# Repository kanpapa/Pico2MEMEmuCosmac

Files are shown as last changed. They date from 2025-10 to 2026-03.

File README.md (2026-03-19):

# Pico2MEMEmuCOSMAC

このリポジトリはkyo-ta04(DragonballEZ)さんの[Pico2ROMEmuBR](https://github.com/kyo-ta04/Pico2ROMEmuBR)のコードを応用して、COSMAC（CDP1802）のROM/RAMエミュレータとして動かしてみた実験的なプロジェクトです。

## 概要
- COSMAC CPUの動作クロックは1.79MHzです。
- ROM/RAMは各32KBを割り当てて確認しましたが、64KBのアドレス空間内であればカスタマイズ可能です。
- ROMにはテストプログラムとしてQ出力のLチカを組み込んでいます。rom_const.cのコメントを参照してください。
- 専用基板Rev.0.1にはSBC1802にあるインジケーターをオプション回路として追加しています。

詳細はソースをご確認ください。

## 回路図
- ブレッドボード版回路図
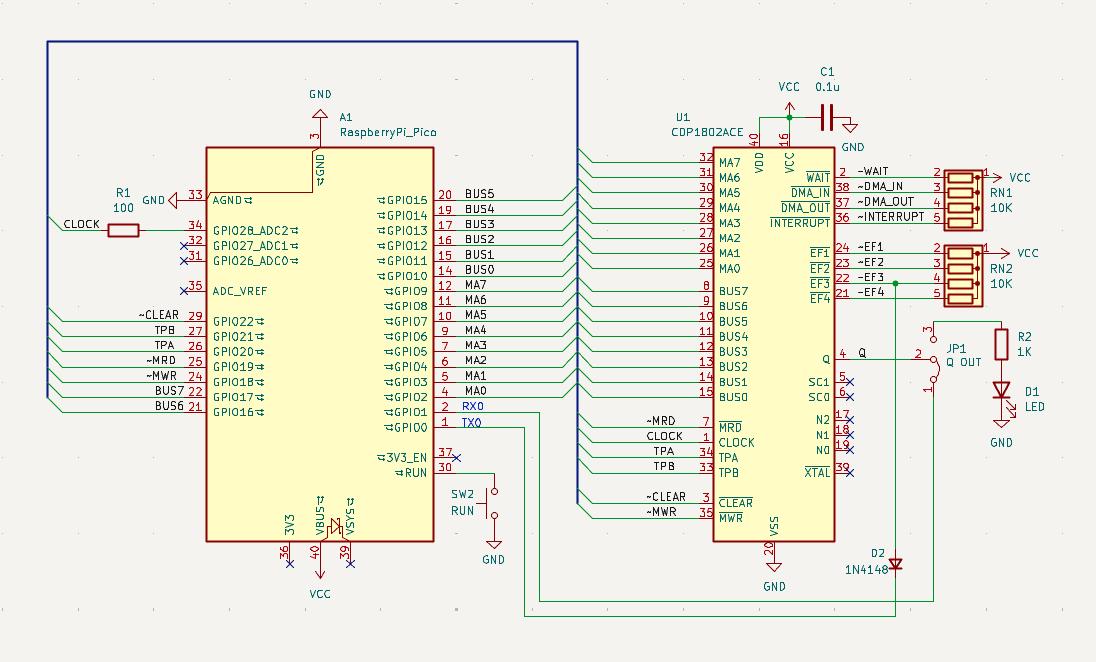
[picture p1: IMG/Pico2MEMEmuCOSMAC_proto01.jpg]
ブレッドボード版回路図

- 専用基板Rev.0.1 回路図
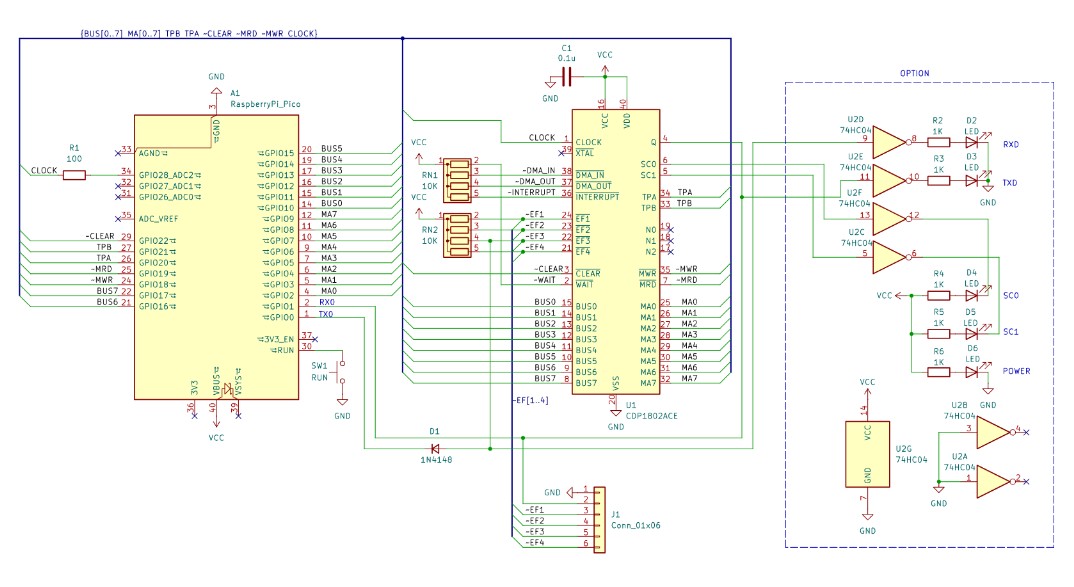
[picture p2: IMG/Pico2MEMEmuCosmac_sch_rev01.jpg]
専用基板回路図

[PDF](/IMG/Pico2MEMEmuCosmac_sch_rev01.pdf)

## PCB
- [KiCADデータ](/kicad)
- [Gerberデータ](/kicad/gerber/)
- PCB 3Dイメージ
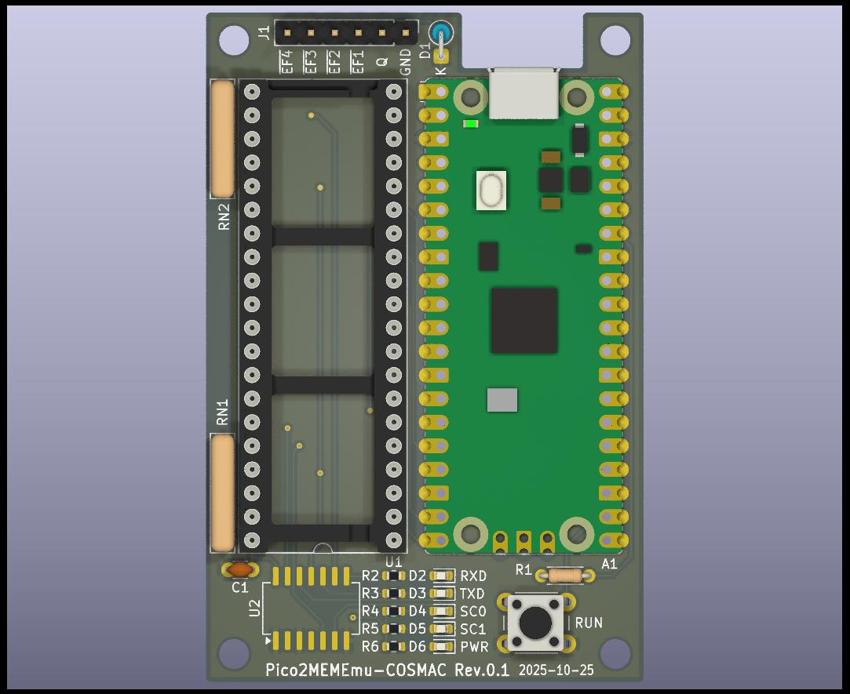
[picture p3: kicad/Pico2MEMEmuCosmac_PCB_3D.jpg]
専用基板Rev.0.1 3Dイメージ


## BOM
|Item|Qty|Reference(s)|Value|Description|Datasheet|
| --- | --- | --- | --- | --- | --- |
|1|1|A1|RaspberryPi_Pico2|Raspberry Pi Pico 2|https://akizukidenshi.com/catalog/g/g129604/|
|2|1|U1|CDP1802ACE|CDP1802ACE microprocessor|http://www.cosmacelf.com/publications/data-sheets/cdp1802.pdf|
|3|1|C1|0.1uF|リード型積層セラミックコンデンサー 0.1μF50V F 2.54mm|https://akizukidenshi.com/catalog/g/g100090/|
|4|1|D1|1N4148|汎用小信号高速スイッチング・ダイオード 1N4148 100V200mA|https://akizukidenshi.com/catalog/g/g100941/|
|5|1|R1|100|カーボン抵抗(炭素皮膜抵抗) 1/6W100Ω|https://akizukidenshi.com/catalog/g/g116101/|
|6|2|RN1,RN2|10K|集合抵抗 4素子 10kΩ|https://akizukidenshi.com/catalog/g/g111909/|
|7|1|SW1|RUN|タクトスイッチ(水色)|https://akizukidenshi.com/catalog/g/g103649/|
|8|1|U1 socket||丸ピンICソケット (40P)|https://akizukidenshi.com/catalog/g/g100034/|
|9※|1|J1|Conn_01x06|ピンヘッダー (L型) 1×6 (6P)|https://akizukidenshi.com/catalog/g/g105336/|
|10※|1|U2|74HC04|6回路入インバーター TC74HC04AF|https://akizukidenshi.com/catalog/g/g111490/|
|11※|5|D2,D3,D4,D5,D6|LED|緑色チップLED 1608 OSG50603C1E|https://akizukidenshi.com/catalog/g/g108275/|
|12※|5|R2,R3,R4,R5,R6|1k|チップ抵抗 1608 1/8W1kΩ|https://akizukidenshi.com/catalog/g/g130351/|

※9～12はオプションです。

## マニュアル
- [Visual Studio Code での Raspberry Pi Pico プロジェクトのビルド方法](/docs/raspberry-pi-pico-vscode-build.md)
- [Lチカの楽しみかた](/docs/blink.md)
- [RCA BASIC3の楽しみかた](/docs/MCBASIC3.md)
- [MCSMP Super Monitor+BASIC3の楽しみかた](/docs/MCSMP20A.md)

## 資料
- ブレッドボードで実験中の様子
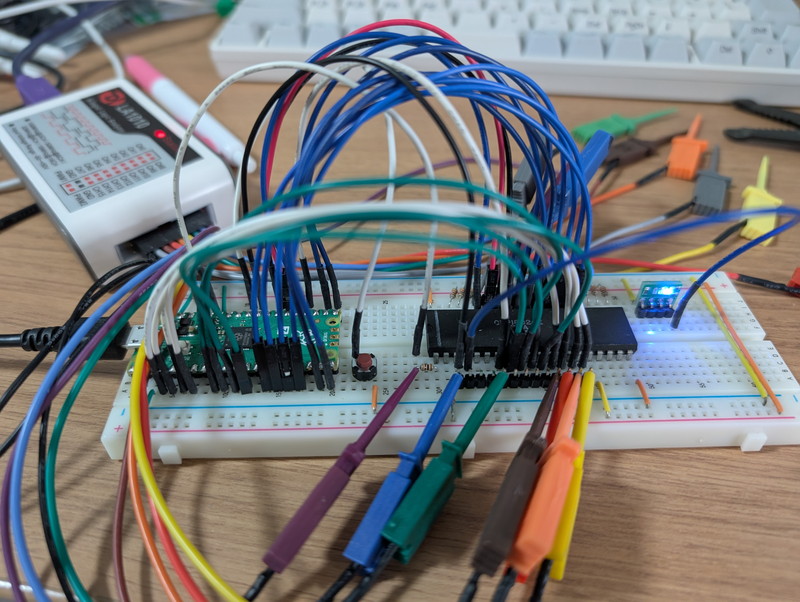
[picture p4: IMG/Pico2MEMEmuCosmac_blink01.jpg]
ブレッドボードで実験中の様子

- 専用基板に実装した状態
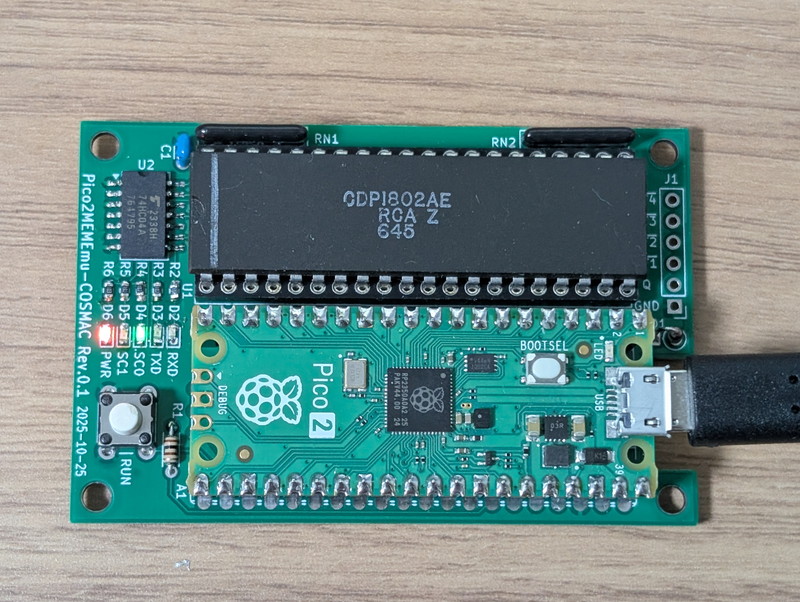
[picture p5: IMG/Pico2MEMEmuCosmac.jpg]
専用基板に実装した状態

- 専用基板で動作中の様子
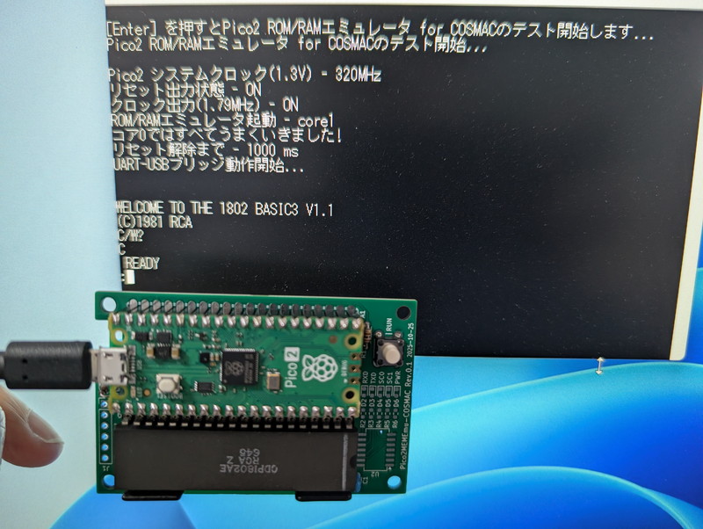
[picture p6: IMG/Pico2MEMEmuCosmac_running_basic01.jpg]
専用基板で動作中の様子


## ライセンス
本プロジェクトのソースコードは[Pico2ROMEmuBR](https://github.com/kyo-ta04/Pico2ROMEmuBR)のライセンスに従います。

## 免責事項
本ソフトウェアは現状のまま提供されます。いかなる損害についても作者は責任を負いません。

## 謝辞
kyo-ta04(DragonballEZ)さんをはじめとするPico2ROMEmuプロジェクトに関わる全ての方々

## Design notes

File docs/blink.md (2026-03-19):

# Lチカの楽しみかた
リポジトリの[rom_const.c](../rom_const.c)にはLチカのサンプルプログラムが含まれています。
これを使って基本的なCOSMACのプログラミングを理解しましょう。

## ソースコード
ソースコードはrom_const.cにコメントとして記載されていますが、blinkの部分だけで動くようにしたものを掲載しておきます。
```
0100-F8 40   START:  LDI #$40  ; Dレジスタに$40を入れる（点滅間隔のウェイトループ値）
0102-B4              PHI 4     ; R4の上位バイトにDレジスタの値を代入する
0103-CD              LSQ       ; Qが1だったら2バイトスキップする
0104-7B              SEQ       ; Qを1にする
0105-38              SKP       ; 次の命令を無条件でスキップする
0106-7A              REQ       ; Qを0にする
0107-24      LOOP1:  DEC 4     ; R4を1減算する
0108-84              GLO 4     ; DレジスタにR4の下位バイトを代入する
0109-3A 07           BNZ LOOP1 ; Dレジスタが0でなければLOOP1にジャンプ
010B-94              GHI 4     ; DレジスタにR4の上位バイトを代入する
010C-3A 07           BNZ LOOP1 ; Dレジスタが0でなければLOOP1にジャンプ
010E-30 00           BR  START ; 最初から繰り返す
```

## ハードウェアの準備
Q出力に抵抗とLEDを接続します。またはオプションのインジケーター回路を実装していればTXDのLEDを点滅することができます。

## ファームウェアの書き込み
[Visual Studio Code での Raspberry Pi Pico プロジェクトのビルド方法](/docs/raspberry-pi-pico-vscode-build.md)を参照してください。

## 点滅間隔を変えてみる
```
0100-F8 40   START:  LDI #$40  ; Dレジスタに$40を入れる（点滅間隔のウェイトループ値）
```
この40の値を変更して、ビルドして書き込んでみてください。点滅間隔が変化します。

## 最小限のプログラムにしてみる
サンプルプログラムでは点滅が肉眼でわかるようにウェイトループが入っていますが、最小限のプログラムにするとたった4バイトになります。
```
0000-7B      START:  SEQ       ; Qを1にする
0000-7A              REQ       ; Qを0にする
000E-30 00           BR  START ; 最初から繰り返す
```
このプログラムではLEDは点灯したままに見えますが、非常に高速で点滅している状態です。オシロスコープを接続するとパルスが出力されていることがわかります。

## COSMAC CPUの仕様
ここでCOSMAC CPUの仕様についてまとめておきます。

### レジスタの構成
Dレジスタは8ビットのアキュムレータです。R0-RFは16ビットの汎用レジスタでどのレジスタもプログラムカウンタやインデックスレジスタにできるユニークな構成です。またQレジスタで1ビットの出力ができます。スタックポインタはありません。汎用レジスタを使って実装することになります。

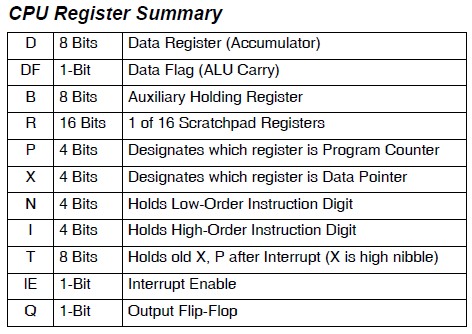
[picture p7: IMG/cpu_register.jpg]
CPU Register Summary


### 命令表
COSMAC CPUの命令セットは１枚の表にまとめることができます。

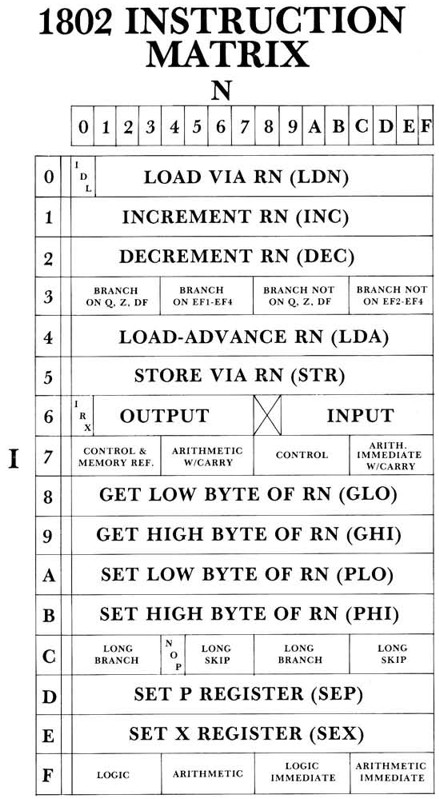
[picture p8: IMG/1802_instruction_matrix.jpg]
1802 INSTRUCTION MATRIX


命令の詳細はデータシートを参照してください。

- [CDP1802A CMOS 8-Bit Microprocessors](https://www.renesas.com/ja/products/cdp1802a)

## アセンブラを使ってみる
少し大きなプログラムに取り組むにはアセンブラが必要になってきます。私が使っているのはSB-ASMというPythonで書かれたアセンブラです。Pythonさえ動けばどの環境でも使うことができます。詳細は公式サイトで確認してください。

- [The SB-Assembler 3](https://www.sbprojects.net/sbasm/)

SB-ASM用のソースコードは[blink1.asm](../samples/blink1.asm)としてリポジトリに登録しています。

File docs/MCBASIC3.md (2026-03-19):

# RCA BASIC3を組み込む方法
ここでは1802メンバーシップカード用に公開されているRCA BASIC3のバイナリデータをPico2MEMEmuCosmacに組み込む手順をまとめました。

## 作業環境
- Ubuntu 24.04
- Pythonが動作すれば他の環境でも同様にできると思います。

## 作業手順
1. [1802メンバーシップカードのホームページ](https://sunrise-ev.com/1802.htm)からRCA BASIC3のバイナリをダウンロードする。

    SoftwareのBASIC for 1802にBASIC3がありますので、`MCBASIC3.bin`をダウンロードします。このバイナリは開始アドレスが0x0000になっていて、16KbyteのROMに書き込めるイメージになっています。

1. RCA BASIC3のバイナリをリポジトリのディレクトリにコピーする。

    ```
    cp MBASIC3.bin ~/Pico2MEMEmuCosmac/.
    ```

1. 現在のROMデータのソースコードを退避する。

    ```
    mv rom_const.c rom_const.c.org
    ```

1. バイナリデータをソースコードに変換するpython3プログラムを実行する。

    ```
    python3 convert_tools/mcbasic3_to_src.py MCBASIC3.bin > rom_const.c
    ```

1. 作成されたソースコードを確認する。MCBASIC3.binが配列として組み込まれていればOKです。

    ```
    cat rom_const.c
    ```

1. `Pico2MEMEmuCosmac.c`のメモリ設定を確認する。ROMが16KByte, RAMの開始が0x8000で32KByteになっていれば問題ありません。

    ```
    #define RAM_START 0x8000 // RAM start address  
    #define ROM_SIZE 0x4000 // ROM size 16k bytes  
    #define RAM_SIZE 0x8000 // RAM size 32k bytes  
    ```

1. Pico2のファームウェアを[ビルド](/docs/raspberry-pi-pico-vscode-build.md)してください。
1. Pico2MEMEmuCosmacのPico2にUSBケーブルでPCを接続し、生成されたファームウェアを書き込みます。
1. PCでターミナルを立ち上げてPico2に接続します。通信速度は9600bps, Data:8bit, Stop:1bit, Parity:Nonです。遅延時間は1文字毎に20ms, 改行毎に500msぐらいが必要です。
1. Enterキーを一度押すと、エミュレーターが動きはじめます。
1. Enrerキーをもう一度押すと、RCA BASIC3が起動します。
1. samplesディレクトリにある[ASCIIART.BAS](../samples/ASCIIART.BAS)をターミナルからアップロードして実行してみてください。

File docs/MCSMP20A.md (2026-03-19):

# 1802メンバーシップカード用スーパーモニタ＋BASIC3を組み込む方法
ここでは1802メンバーシップカード用に公開されているMCSMP Super Monitor Program plus BASIC3のバイナリデータをPico2MEMEmuCosmacに組み込む手順をまとめました。

## 作業環境
- Ubuntu 24.04
- Pythonが動作すれば他の環境でも同様にできると思います。

## 作業手順
1. [1802メンバーシップカードのホームページ](https://sunrise-ev.com/1802.htm)からMCSMP Super Monitor Program plus BASIC3のバイナリをダウンロードする。

    SoftwareのMonitor programsにMCSMP Super Monitor Program plus BASIC3がありますので、`MCSMP20A.bin`をダウンロードします。このバイナリは開始アドレスが0x0000になっていて、32KbyteのROMに書き込めるイメージになっています。

1. MCSMP20Aのバイナリをリポジトリのディレクトリにコピーする。

    ```
    cp MCSMP20A.bin ~/Pico2MEMEmuCosmac/.
    ```

1. 現在のROMデータのソースコードを退避する。

    ```
    mv rom_const.c rom_const.c.org
    ```

1. バイナリデータをソースコードに変換するpython3プログラムを実行する。

    ```
    python3 convert_tools/mcsmp20a_to_src.py MCSMP20A.bin > rom_const.c
    ```

1. 作成されたソースコードを確認する。MCSMP20A.binが配列として組み込まれていればOKです。

    ```
    cat rom_const.c
    ```

1. `Pico2MEMEmuCosmac.c`のメモリ設定を以下のように変更する。ROMを32KByteを変更し, RAMの開始が0x8000で32KByteになっていれば問題ありません。

    ```
    #define RAM_START 0x8000 // RAM start address  
    //#define ROM_SIZE 0x4000 // ROM size 16k bytes  
    #define ROM_SIZE 0x8000 // ROM size 32k bytes  
    #define RAM_SIZE 0x8000 // RAM size 32k bytes  
    ```

1. Pico2のファームウェアを[ビルド](/docs/raspberry-pi-pico-vscode-build.md)してください。
1. Pico2MEMEmuCosmacのPico2にUSBケーブルでPCを接続し、生成されたファームウェアを書き込みます。
1. PCでターミナルを立ち上げてPico2に接続します。通信速度は9600bps, Data:8bit, Stop:1bit, Parity:Nonです。遅延時間は1文字毎に20ms, 改行毎に500msぐらいが必要です。
1. Enterキーを一度押すと、エミュレーターが動きはじめます。
1. Enterキーをもう一度押すと、スーパーモニタが起動します。モニタとしての機能を楽しんでください。
1. モニタのBコマンドでBASIC3が起動します。samplesディレクトリにある[ASCIIART.BAS](../samples/ASCIIART.BAS)をターミナルからアップロードして実行してみてください。

## 動作中の画面
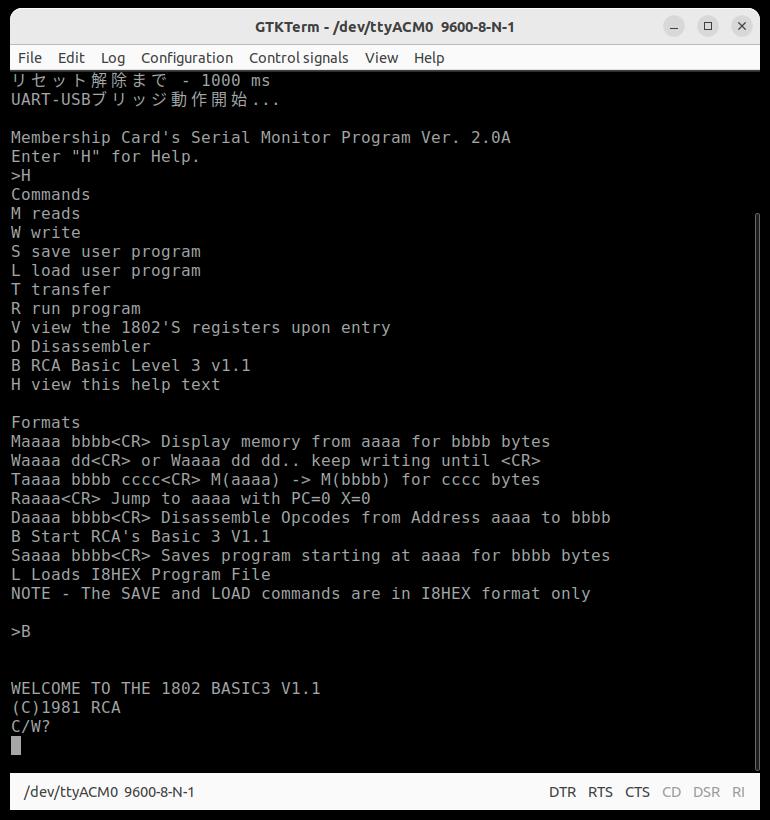
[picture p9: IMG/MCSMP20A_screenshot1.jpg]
MCSMP20A_screenshot1


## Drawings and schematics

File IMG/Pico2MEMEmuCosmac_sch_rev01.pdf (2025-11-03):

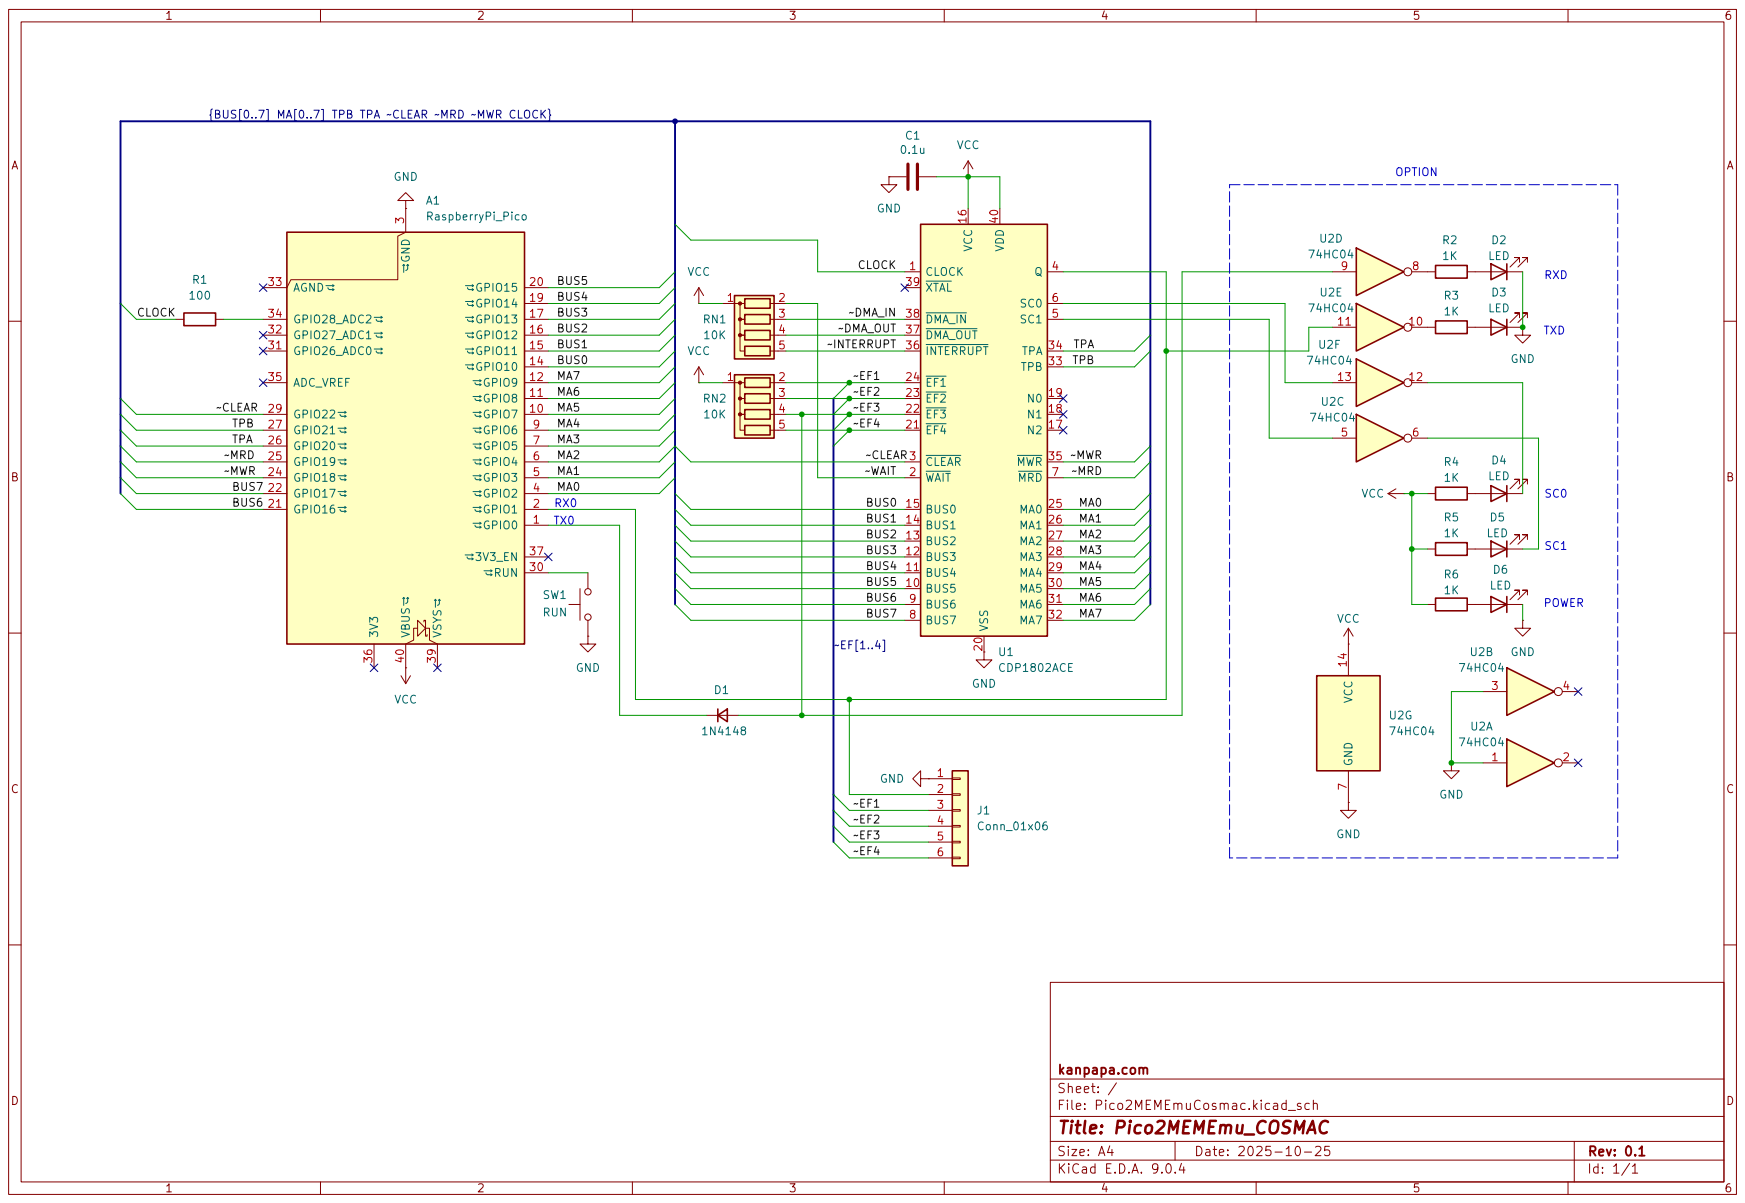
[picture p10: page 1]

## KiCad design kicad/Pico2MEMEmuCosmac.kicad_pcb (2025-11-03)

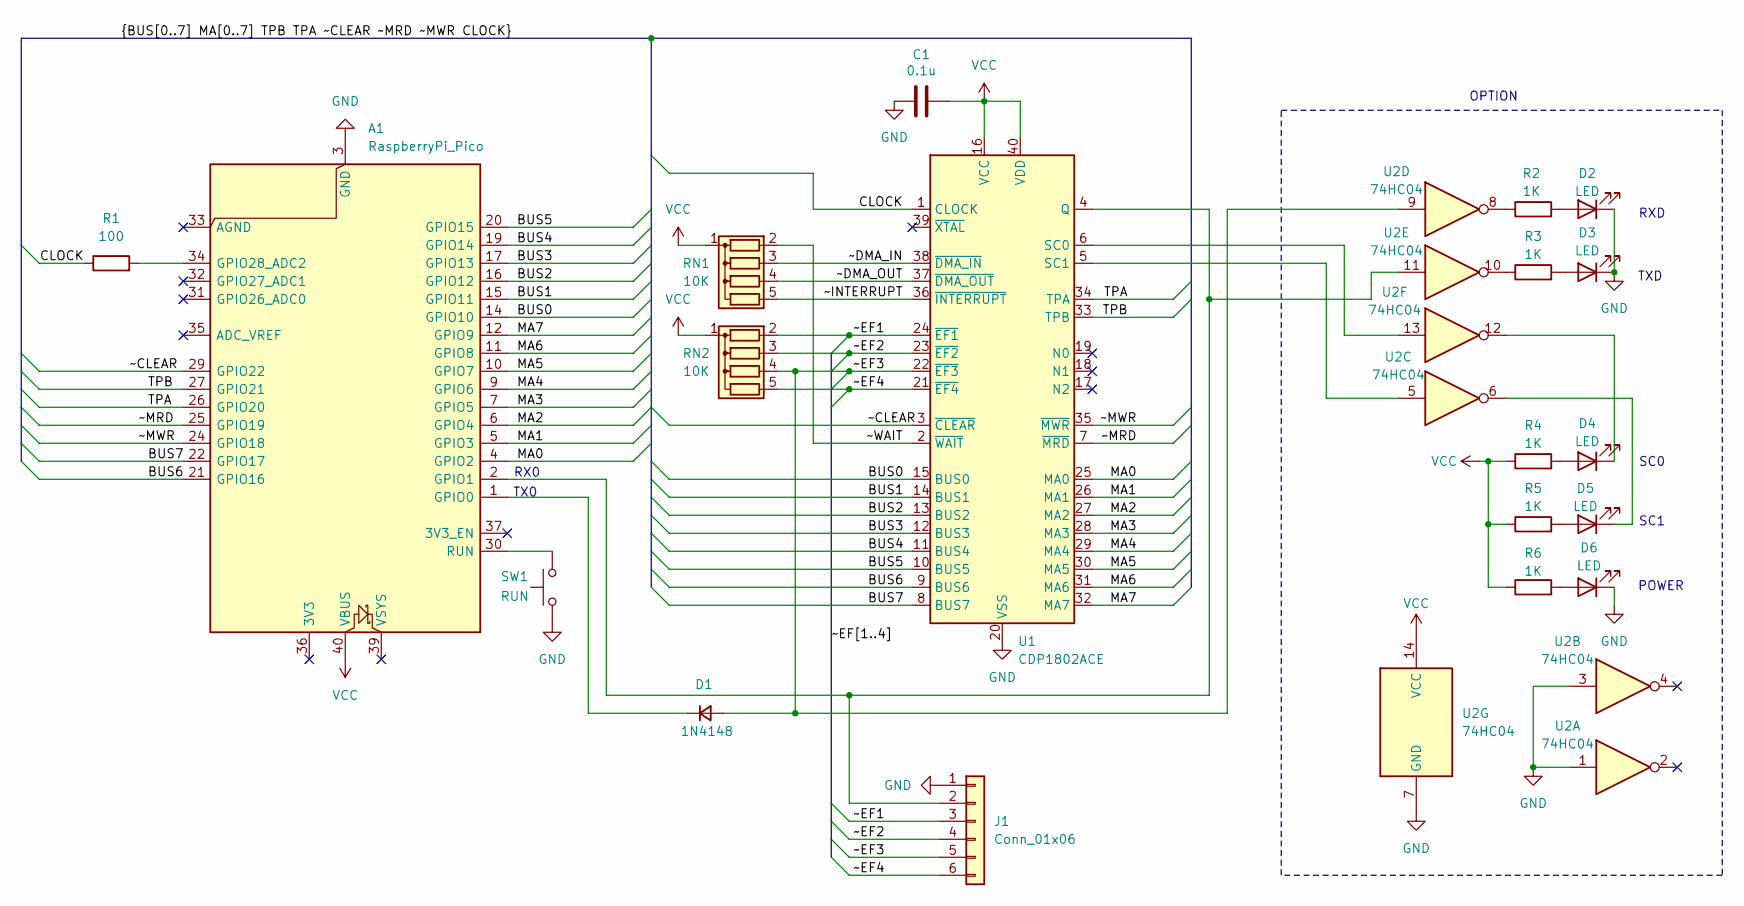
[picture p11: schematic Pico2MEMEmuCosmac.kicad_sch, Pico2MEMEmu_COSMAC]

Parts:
A1: RaspberryPi_Pico; RaspberryPi_Pico_Common_Unspecified
C1: 0.1u; C_Disc_D3.0mm_W1.6mm_P2.50mm
D1: 1N4148; D_DO-35_SOD27_P2.54mm_Vertical_KathodeUp
D2, D3, D4, D5, D6: LED; LED_0603_1608Metric
J1: Conn_01x06; PinHeader_1x06_P2.54mm_Vertical
R1: 100; R_Axial_DIN0204_L3.6mm_D1.6mm_P5.08mm_Horizontal
R2, R3, R4, R5, R6: 1K; R_0603_1608Metric
RN1, RN2: 10K; R_Array_SIP5
SW1: RUN; SW_PUSH_6mm
U1: CDP1802ACE; DIP-40_W15.24mm_Socket_LongPads
U2: 74HC04; SO-14_5.3x10.2mm_P1.27mm

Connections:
/BUS0: A1.14 (GPIO10), U1.15 (BUS0)
/BUS1: A1.15 (GPIO11), U1.14 (BUS1)
/BUS2: A1.16 (GPIO12), U1.13 (BUS2)
/BUS3: A1.17 (GPIO13), U1.12 (BUS3)
/BUS4: A1.19 (GPIO14), U1.11 (BUS4)
/BUS5: A1.20 (GPIO15), U1.10 (BUS5)
/BUS6: A1.21 (GPIO16), U1.9 (BUS6)
/BUS7: A1.22 (GPIO17), U1.8 (BUS7)
/CLOCK: R1.1, U1.1 (CLOCK)
/MA0: A1.4 (GPIO2), U1.25 (MA0)
/MA1: A1.5 (GPIO3), U1.26 (MA1)
/MA2: A1.6 (GPIO4), U1.27 (MA2)
/MA3: A1.7 (GPIO5), U1.28 (MA3)
/MA4: A1.9 (GPIO6), U1.29 (MA4)
/MA5: A1.10 (GPIO7), U1.30 (MA5)
/MA6: A1.11 (GPIO8), U1.31 (MA6)
/MA7: A1.12 (GPIO9), U1.32 (MA7)
/TPA: A1.26 (GPIO20), U1.34 (TPA)
/TPB: A1.27 (GPIO21), U1.33 (TPB)
/~CLEAR: A1.29 (GPIO22), U1.3 (~CLEAR)
/~DMA_IN: RN1.3 (R2), U1.38 (~DMA_IN)
/~DMA_OUT: RN1.4 (R3), U1.37 (~DMA_OUT)
/~EF1: J1.3, RN2.2 (R1), U1.24 (~EF1)
/~EF2: J1.4, RN2.3 (R2), U1.23 (~EF2)
/~EF3: D1.2 (A), J1.5, RN2.4 (R3), U1.22 (~EF3), U2.9
/~EF4: J1.6, RN2.5 (R4), U1.21 (~EF4)
/~INTERRUPT: RN1.5 (R4), U1.36 (~INTERRUPT)
/~MRD: A1.25 (GPIO19), U1.7 (~MRD)
/~MWR: A1.24 (GPIO18), U1.35 (~MWR)
/~WAIT: RN1.2 (R1), U1.2 (~WAIT)
GND: A1.3 (GND), A1.8 (GND), A1.13 (GND), A1.18 (GND), A1.23 (GND), A1.28 (GND), A1.38 (GND), C1.2, D2.1 (K), D3.1 (K), D6.1 (K), J1.1, SW1.2, U1.20 (VSS), U2.1, U2.3, U2.7 (GND)
unnamed: A1.1 (GPIO0), D1.1 (K)
unnamed: A1.2 (GPIO1), J1.2, U1.4 (Q), U2.11
unnamed: A1.34 (GPIO28_ADC2), R1.2
unnamed: A1.30 (RUN), SW1.1
unnamed: D2.2 (A), R2.2
unnamed: D3.2 (A), R3.2
unnamed: D4.2 (A), R4.2
unnamed: D4.1 (K), U2.12
unnamed: D5.2 (A), R5.2
unnamed: D5.1 (K), U2.6
unnamed: D6.2 (A), R6.2
unnamed: R2.1, U2.8
unnamed: R3.1, U2.10
unnamed: U1.6 (SC0), U2.13
unnamed: U1.5 (SC1), U2.5
VCC: A1.40 (VBUS), C1.1, R4.1, R5.1, R6.1, RN1.1 (common), RN2.1 (common), U1.16 (VCC), U1.40 (VDD), U2.14 (VCC)

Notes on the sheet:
SC1
RX0
TXD
TX0
OPTION
POWER
RXD
SC0

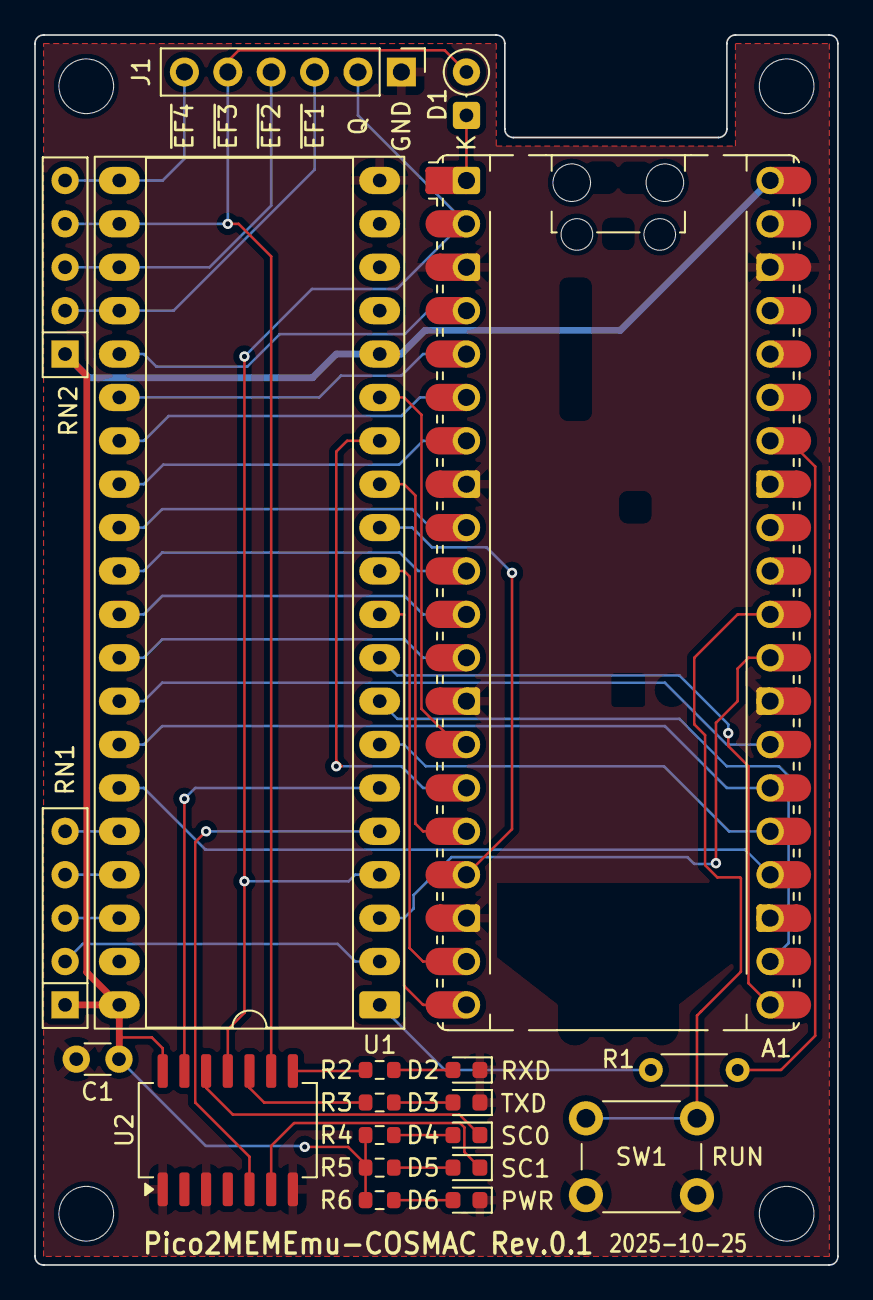
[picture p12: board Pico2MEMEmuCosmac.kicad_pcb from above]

Board: 2 copper layers, 47.0 x 72.0 mm, 24 parts (0 on the bottom side), 47 nets.

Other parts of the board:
MH1, MH2, MH3, MH4: MountingHole_3.2mm_M3

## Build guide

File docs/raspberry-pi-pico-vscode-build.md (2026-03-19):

# Visual Studio Code での Raspberry Pi Pico プロジェクトのビルド方法

Raspberry Pi Pico2のファームウェアのビルド環境はWindowsだとVisual Studio Codeの拡張機能を使用するのがおすすめです。  

Windowsの場合はコンパイルに必要なツールは自動的にユーザディレクトリの.pico-sdkディレクトリにインストールされます。

## Pico2開発環境の準備  

1. Visual Studio Codeをインストールしてください。

    https://code.visualstudio.com/

1. 拡張機能でRaspberry Pi Picoをインストールしてください。

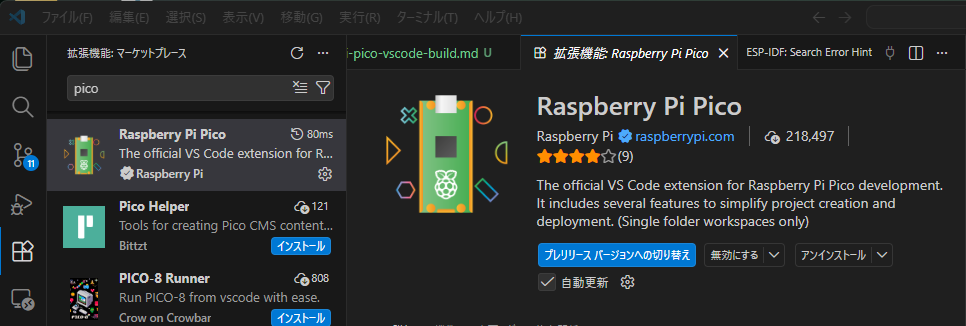
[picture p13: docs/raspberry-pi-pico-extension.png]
Raspberry Pi Pico Extension
    

## プロジェクトのインポート

1. VSCodeで`ファイル`→`新しいウインドウ`を開きます。

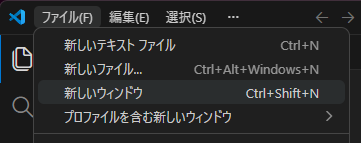
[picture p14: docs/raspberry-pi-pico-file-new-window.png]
New window
    

1. `Gitリポジトリのクローン…`をクリックします。

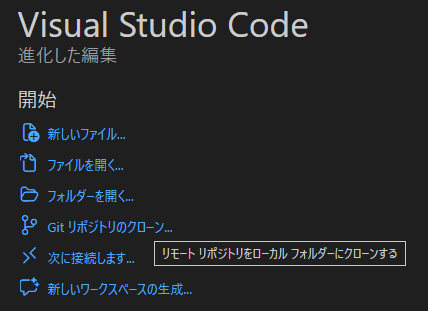
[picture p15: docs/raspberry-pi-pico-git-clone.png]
Git clone
    

1. リポジトリのURLを入力します。

    https://github.com/kanpapa/Pico2MEMEmuCosmac.git

    Git URL

1. リポジトリを保存するフォルダを選択します。ユーザディレクトリの直下で良いでしょう。
1. リポジトリの保存が終わると以下のようなメニューが表示されます。

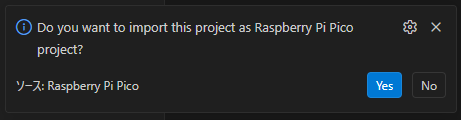
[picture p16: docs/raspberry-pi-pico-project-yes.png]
Raspberry Pi Pico project?
    

1. ここでYESを押すと以下のインポート画面になります。

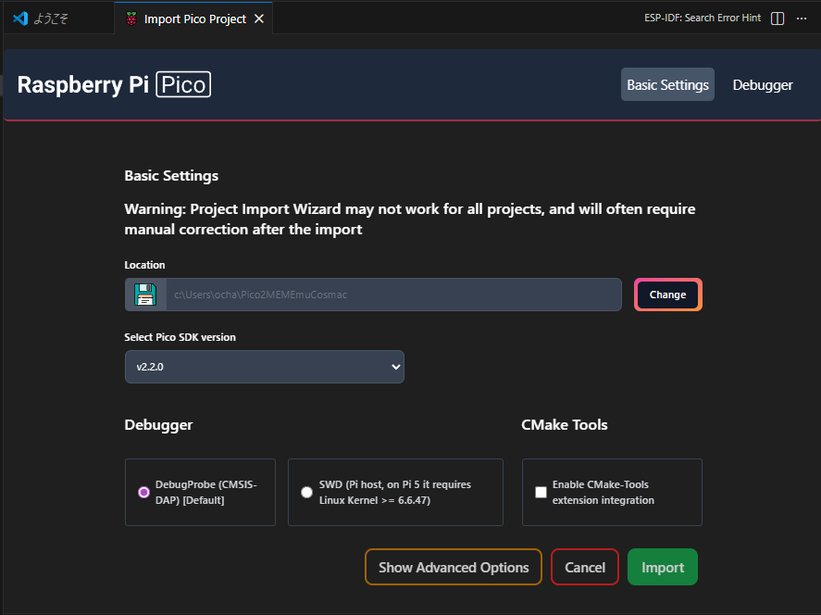
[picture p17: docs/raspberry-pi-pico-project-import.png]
Raspberry Pi pico import project
    

    Locationが正しいことを確認して`import`を押してください。

1. 正常にインポートできれば、.vscodeフォルダが作成され、ビルドに必要な設定が保存されます。

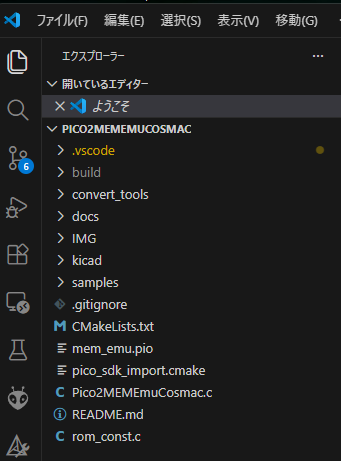
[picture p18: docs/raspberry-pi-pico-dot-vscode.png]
created .vscode
    

## Pico2のファームウェアのビルド

1. アクティビティバーにあるPicoのアイコンをクリックすると以下のメニューが表示されます。

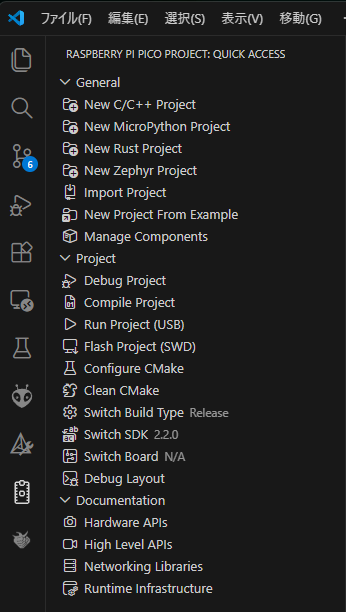
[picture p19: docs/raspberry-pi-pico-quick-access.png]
Quick access menu
    

1. このメニューの`Compile Project`をクリックします。
1. 正常にビルドが終了すればbuildディレクトリにファームウェア`Pico2MEMEmuCosmac.uf2`が生成されます。  

## ファームウェアのインストール

1. Pico2をUSBケーブルでPCに接続するとPico2のフォルダにアクセスできます。
1. 生成されたファームウェア`Pico2MEMEmuCosmac.uf2`をこのフォルダにドラッグ＆ドロップすることでPico2が新しいファームウェアで動き始めます。

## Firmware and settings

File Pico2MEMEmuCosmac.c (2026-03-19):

// Pico2MEMEmuCosmac.C
// COSMAC test Version
//
// Based on kyo-ta04(DragonballEZ) Pico2ROMEmuBR.c
// https://github.com/kyo-ta04/Pico2ROMEmuBR
//

#include <stdio.h>
#include <string.h>
#include "pico/stdlib.h"
#include "hardware/vreg.h"
#include "hardware/pio.h"
#include "hardware/clocks.h"
#include "hardware/uart.h"
#include "hardware/pll.h"
#include "pico/multicore.h"
#include "mem_emu.pio.h"
#include "rom_const.c" 

#define DATA_PINS_BASE 10  // GP10～GP17 (D0-D7 8bit)
#define ADDR_PINS_BASE 2   // GP2～GP9 (MA0-MA7 8bit)
#define MWR_PIN 18
#define MRD_PIN 19
#define TPA_PIN 20
#define TPB_PIN 21
#define RESETOUT_PIN 22     // GP22 (リセット出力)
#define CLKOUT_PIN 28       // GP28 (クロック出力)

// UART0の設定
#define UART_ID uart0
#define BAUD_RATE 9600
#define UART_TX_PIN 0
#define UART_RX_PIN 1

#define FLAG_VALUE 123

// ROM512byte, RAM512byte (Blink test)
#define RAM_START 0x1000
#define RAM_SIZE 512 // RAM size 0.5k bytes
#define ROM_SIZE 512 // ROM size 0.5k bytes

// ROM16K, RAM32K (MCBASIC3.bin)
//#define RAM_START 0x8000 // RAM start address
//#define ROM_SIZE 0x4000 // ROM size 16k bytes
//#define RAM_SIZE 0x8000 // RAM size 32k bytes

// ROM32K, RAM32K (MCSMP20A.bin)
//#define RAM_START 0x8000 // RAM start address
//#define ROM_SIZE 0x8000 // ROM size 32k bytes
//#define RAM_SIZE 0x8000 // RAM size 32k bytes

// PIO初期化
PIO pio = pio0;

const uint sm_addr = 0;
const uint sm_write = 1;
const uint sm_clock = 2;
const uint sm_reset = 3;

// IRQハンドラとメインループで共有するアドレス
volatile uint16_t current_address = 0;

uint8_t rom_data[ROM_SIZE] __attribute__((section(".data")));
uint8_t ram_data[RAM_SIZE];

// コア1のエントリポイント
// core1_entry()はPIOの状態マシンを実行し、ROMデータを送信する  
__attribute__((noinline)) void __time_critical_func(core1_entry)(void) {
    multicore_fifo_push_blocking(FLAG_VALUE);
    uint32_t g = multicore_fifo_pop_blocking();
    while (true) {
        // アドレス取得SMのFIFOをチェック
        if (!pio_sm_is_rx_fifo_empty(pio, sm_addr)) {
            // ラッチしたアドレスの取り込み
            current_address = pio_sm_get_blocking(pio, sm_addr);
            // ★★★ デバッグ用に追加 ★★★
            //printf("Address captured: 0x%04X\n", current_address);
    
            // readなのかwriteなのかわからないがとりあえずメモリのデータを送信し、あとはsm_addrにまかせる。
            uint8_t data_to_send = 0xFF;
            if (current_address < ROM_SIZE) {
                data_to_send = rom_data[current_address];
            } else if (current_address >= RAM_START && current_address < (RAM_START + RAM_SIZE)) {
                data_to_send = ram_data[current_address - RAM_START];
            }
            // ★★★ デバッグ用に追加 ★★★
            //printf("  -> Sending data: 0x%02X for address 0x%04X\n", data_to_send, current_address);
            pio_sm_put_blocking(pio, sm_addr, data_to_send);
        }

        // 書き込みSMのFIFOをチェック
        if (!pio_sm_is_rx_fifo_empty(pio, sm_write)) {
            // ここにデータがきたら無条件でメモリに書き込む
            uint8_t data_written = (uint8_t)pio_sm_get_blocking(pio, sm_write);
            // ★★★ デバッグ用に追加 ★★★
            //printf("  -> Receving data: 0x%02X for address 0x%04X\n", data_written, current_address);
            
            // RAM領域への書き込みのみ処理
            if (current_address >= RAM_START && current_address < (RAM_START + RAM_SIZE)) {
                ram_data[current_address - RAM_START] = data_written;
            }
        }
    }
}

// rom_basic[]をrom_data[]にコピーする初期化ルーチン
void init_rom_basic_code(void) {
    // z80_binary[]の内容をrom_data[]の先頭にコピー
    memcpy(rom_data, rom_basic, sizeof(rom_basic));
    // 残りのrom[]を0xFFで埋める（8Kバイトまで）
    memset(rom_data + sizeof(rom_basic), 0xFF, ROM_SIZE - sizeof(rom_basic));
}

// QSPIクロックを調整する関数
void set_qspi_clock_divider(uint32_t sys_clock_khz, uint32_t qspi_max_khz) {
    uint32_t divider = (sys_clock_khz + qspi_max_khz - 1) / qspi_max_khz;
    clock_configure(clk_peri, 0, CLOCKS_CLK_PERI_CTRL_AUXSRC_VALUE_CLKSRC_PLL_SYS, sys_clock_khz * 1000, sys_clock_khz * 1000 / divider);
}

__attribute__((noinline)) int __time_critical_func(main)(void) {
    uint32_t sysclk = 320 * 1000;           // Pico2 システムクロック 280/320/360MHz 
    vreg_set_voltage(VREG_VOLTAGE_1_30);    // 電圧を1.3Vに設定
    sleep_ms(100);                          // 電圧安定のための待機
    set_sys_clock_khz(sysclk, true);        // 高速動作
    set_qspi_clock_divider(sysclk, 133000); // QSPIクロックを133MHz以下に

    stdio_init_all();
    setbuf(stdout, NULL);           // 標準出力のバッファリングを無効化 

    // UART0の初期化
    uart_init(UART_ID, BAUD_RATE);
    // UARTピンの設定（GPIO0=TX, GPIO1=RX）
    gpio_set_function(UART_TX_PIN, GPIO_FUNC_UART);
    gpio_set_function(UART_RX_PIN, GPIO_FUNC_UART);

    // Programmable I/O(PIO)初期化
    uint offset_addr = pio_add_program(pio, &cdp1802_get_address_program); // 命令用のメモリーにアセンブラのプログラムを登録します
    uint offset_write = pio_add_program(pio, &cdp1802_write_mem_program);

    // --- 各ステートマシンの設定 ---
    // 0. アドレス取得＆読み出し用SM (sm_addr)
    pio_sm_config c_addr = cdp1802_get_address_program_get_default_config(offset_addr);
    sm_config_set_in_pins(&c_addr, ADDR_PINS_BASE);
    sm_config_set_out_pins(&c_addr, DATA_PINS_BASE, 8);
    sm_config_set_jmp_pin(&c_addr, MRD_PIN); // MRDをJMPピンとして設定
    // PIOが制御するピンの方向を設定
    pio_sm_set_consecutive_pindirs(pio, sm_addr, ADDR_PINS_BASE, 8, false); // ADDRESSバスは入力
    pio_sm_set_consecutive_pindirs(pio, sm_addr, TPA_PIN, 1, false);  // TPAは入力
    pio_sm_set_consecutive_pindirs(pio, sm_addr, TPB_PIN, 1, false);  // TPBは入力
    pio_sm_set_consecutive_pindirs(pio, sm_addr, DATA_PINS_BASE, 8, false); // 初期は入力
    pio_sm_set_consecutive_pindirs(pio, sm_addr, MRD_PIN, 1, false);  // MRDは入力
    
    // 1. 書き込み用SM (sm_write)
    pio_sm_config c_write = cdp1802_write_mem_program_get_default_config(offset_write);
    sm_config_set_in_pins(&c_write, DATA_PINS_BASE); // DATAバスは入力
    // PIOが制御するピンの方向を設定
    pio_sm_set_consecutive_pindirs(pio, sm_write, MWR_PIN, 1, false); // MWR_PINは入力
    pio_sm_set_consecutive_pindirs(pio, sm_write, DATA_PINS_BASE, 8, false); // DATAバスは入力

    // 2. CPUクロック生成用SM (sm_clock)
    uint offset_clock = pio_add_program(pio, &clk_out_program);
    pio_sm_config c_clock = clk_out_program_get_default_config(offset_clock);
 
    // 3. RESET信号生成用SM (sm_reset)
    uint offset_reset = pio_add_program(pio, &reset_out_program);
    pio_sm_config c_reset = reset_out_program_get_default_config(offset_reset);

    // GPIO初期化
    // GP10-22: 出力(8ピン BUS0-BUS7)
    for (int i = 0; i < 8; i++) {
        pio_gpio_init(pio, DATA_PINS_BASE + i);
    }
    // GP2-9：入力(8ピン MA0-MA7)
    for (int i = 0; i < 8; i++) {
      pio_gpio_init(pio, ADDR_PINS_BASE + i);
    }
    
    pio_gpio_init(pio, RESETOUT_PIN); // リセット出力ピン(GP25)の初期化
    pio_gpio_init(pio, MRD_PIN); // MRDピン(GP18)の初期化
    pio_gpio_init(pio, MWR_PIN); // MWRピン(GP19)の初期化
    pio_gpio_init(pio, TPA_PIN); // TPAピン(GP20)の初期化
    pio_gpio_init(pio, TPB_PIN); // TPBピン(GP21)の初期化
    pio_gpio_init(pio, CLKOUT_PIN); // CLK出力ピン(GP28)の初期化

    // Pullup
    gpio_set_pulls(MRD_PIN, true, false);
    gpio_set_pulls(MWR_PIN, true, false);
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

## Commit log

2025-10-12 TPAを実装
2025-10-12 ROMデータのコメントを修正
2025-10-12 コメントのアセンブリリストのLBRのコードを修正
2025-10-12 DATA BUSとADDRESS BUSを入れ替えた
2025-10-13 MWRとMRDのGPIOを入れ替えた。上位アドレスラッチはMRDではなくTPAのたち下がりに修正。
2025-10-13 不要なコメントを削除
2025-10-13 READMEと回路図を追加
2025-10-13 README_COSMACの文面を修正
2025-10-13 README_COSMACの体裁を調整
2025-10-13 README_COSMACの文章を修正
2025-10-13 README_COSMACに概要を追記
2025-10-13 MRDのチェックが漏れていたので追加
2025-10-16 MWRの実験的な実装
2025-10-16 IDIOTモニタをROMに入れて動作した
2025-10-17 不要なコードの削除とCPUクロック表示の修正
2025-10-17 バイナリからソースコードに変換するツールを追加
2025-10-17 回路図にシリアル通信を追加
2025-10-26 COSMACに特化した機能のため、Pico2ROMEmuBRからリポジトリを分離しました。
2025-10-26 リポジトリ分離に合わせてREADMEを見直し
2025-10-26 Kicadデータを追加
    [Pico2MEMEmuCosmac.kicad_pcb, Pico2MEMEmuCosmac.kicad_sch]
2025-10-26 3D Viewの画像を追加
2025-10-26 Rev.0.1基板の回路図を追加
2025-11-02 Rev.0.1基板のガーバーデータを追加
    [Pico2MEMEmuCosmac-B_Cu.gbl, Pico2MEMEmuCosmac-B_Mask.gbs, Pico2MEMEmuCosmac-B_Silkscreen.gbo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]
2025-11-03 BOMの追加とガーバーデータのリンクを追加
2025-11-03 回路図のPDFをリンク
2025-11-03 MCBASIC3の組み込み方法を追加
2025-11-03 RCA BASIC3の組み込みかたのリンクを追加
2025-11-03 MCSMP20Aの組み込みかたを追加
2025-11-03 MCSMP20Aのスクリーンショットを追加
2025-11-03 Blinkプログラムを整理し、IDIOTモニタを削除
2025-11-03 不要なコメントの削除
2025-11-03 メモリ設定をパターンで分けた
2025-11-04 Lチカの説明と各種写真の追加
2025-11-04 ファイル名の誤りを修正
2026-03-18 VSCode設定の修正
2026-03-18 サンプルとしてblinkのuf2ファイルを追加
2026-03-19 ファームウェアのビルド方法を補足
2026-03-19 ファイル名の変更等大幅に見直し
2026-03-19 VSCodeでのビルド方法を追記
2026-03-19 パスを修正
2026-03-19 blinkのサンプルuf2を登録
2026-03-19 blink1.asmのアセンブルリストを追加
2026-03-19 キャプチャを追加
2026-03-19 キャプチャの配置を修正
2026-03-19 コメントを修正
